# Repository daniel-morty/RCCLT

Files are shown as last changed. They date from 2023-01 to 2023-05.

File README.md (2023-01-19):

# ESPNOW Basic Example

This is a very basic example to get up and running with ESP-NOW using ESP-IDF. While the included example in the IDF is comprehensive and secure, this example should allow for faster understanding and testing.

The slave will simply send a random value and the state of GPIO 0 (typically attached to a button named '0', 'BOOT' or 'PROG' on most dev boards) to the broadcast address. The master will receive and log it.

To customise the payload, simply change the struct in espnow_basic_config.h, and edit my_slave.c and my_master.c to populate and parse respectively.

See espnow_basic_config.h for more.

============================================================
mac of remote/car pair 1
remote	f4:12:fa:1b:3e:b0
car:	f4:12:fa:1b:84:88

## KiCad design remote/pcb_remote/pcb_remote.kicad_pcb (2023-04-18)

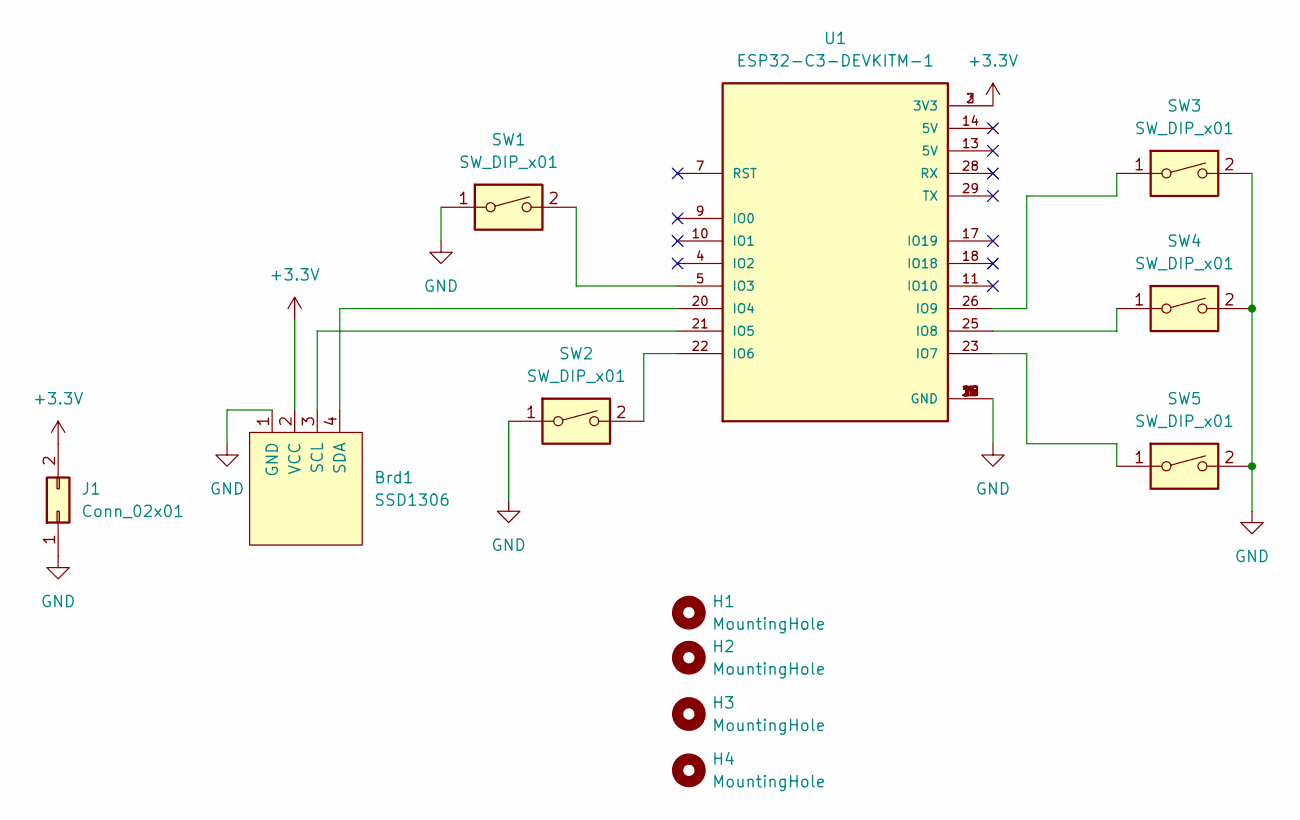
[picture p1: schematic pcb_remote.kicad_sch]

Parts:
Brd1: SSD1306; 128x64OLED
H1, H2, H3, H4: MountingHole; MountingHole_2.2mm_M2
J1: Conn_02x01; PinHeader_1x02_P2.54mm_Vertical
SW1, SW2, SW3, SW4, SW5: SW_DIP_x01; SW_PUSH-12mm
U1: ESP32-C3-DEVKITM-1; XCVR_ESP32-C3-DEVKITM-1

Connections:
+3V3: Brd1.2 (VCC), J1.2, U1.2 (3V3), U1.3 (3V3)
GND: Brd1.1 (GND), J1.1, SW1.1, SW2.1, SW3.2, SW4.2, SW5.2, U1.1 (GND), U1.6 (GND), U1.8 (GND), U1.12 (GND), U1.15 (GND), U1.16 (GND), U1.19 (GND), U1.24 (GND), U1.27 (GND), U1.30 (GND)
unnamed: Brd1.3 (SCL), U1.21 (IO5)
unnamed: Brd1.4 (SDA), U1.20 (IO4)
unnamed: SW1.2, U1.5 (IO3)
unnamed: SW2.2, U1.22 (IO6)
unnamed: SW3.1, U1.26 (IO9)
unnamed: SW4.1, U1.25 (IO8)
unnamed: SW5.1, U1.23 (IO7)

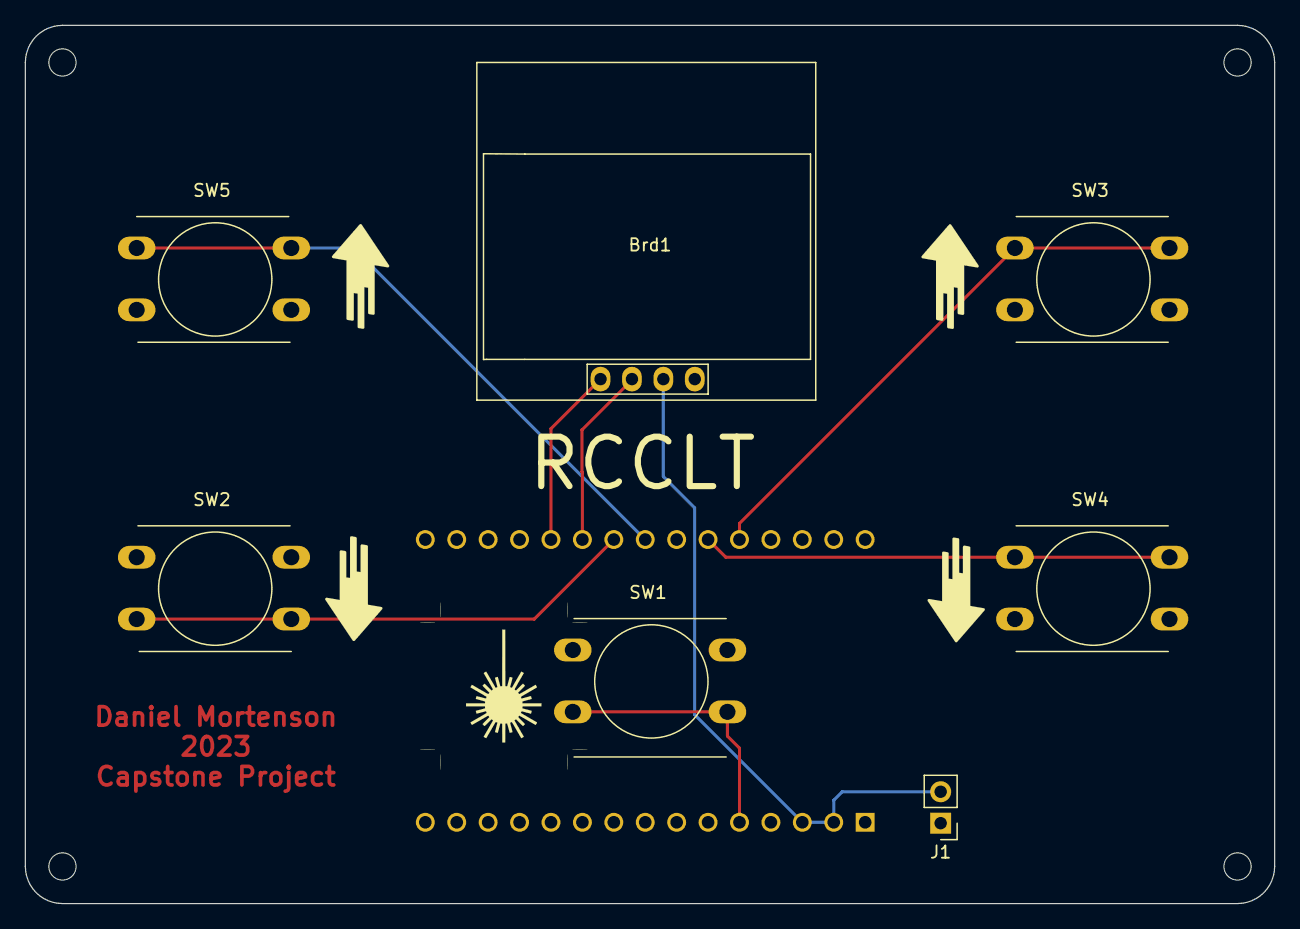
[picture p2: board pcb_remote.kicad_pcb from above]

Board: 2 copper layers, 101.0 x 71.0 mm, 12 parts (1 on the bottom side), 9 nets.

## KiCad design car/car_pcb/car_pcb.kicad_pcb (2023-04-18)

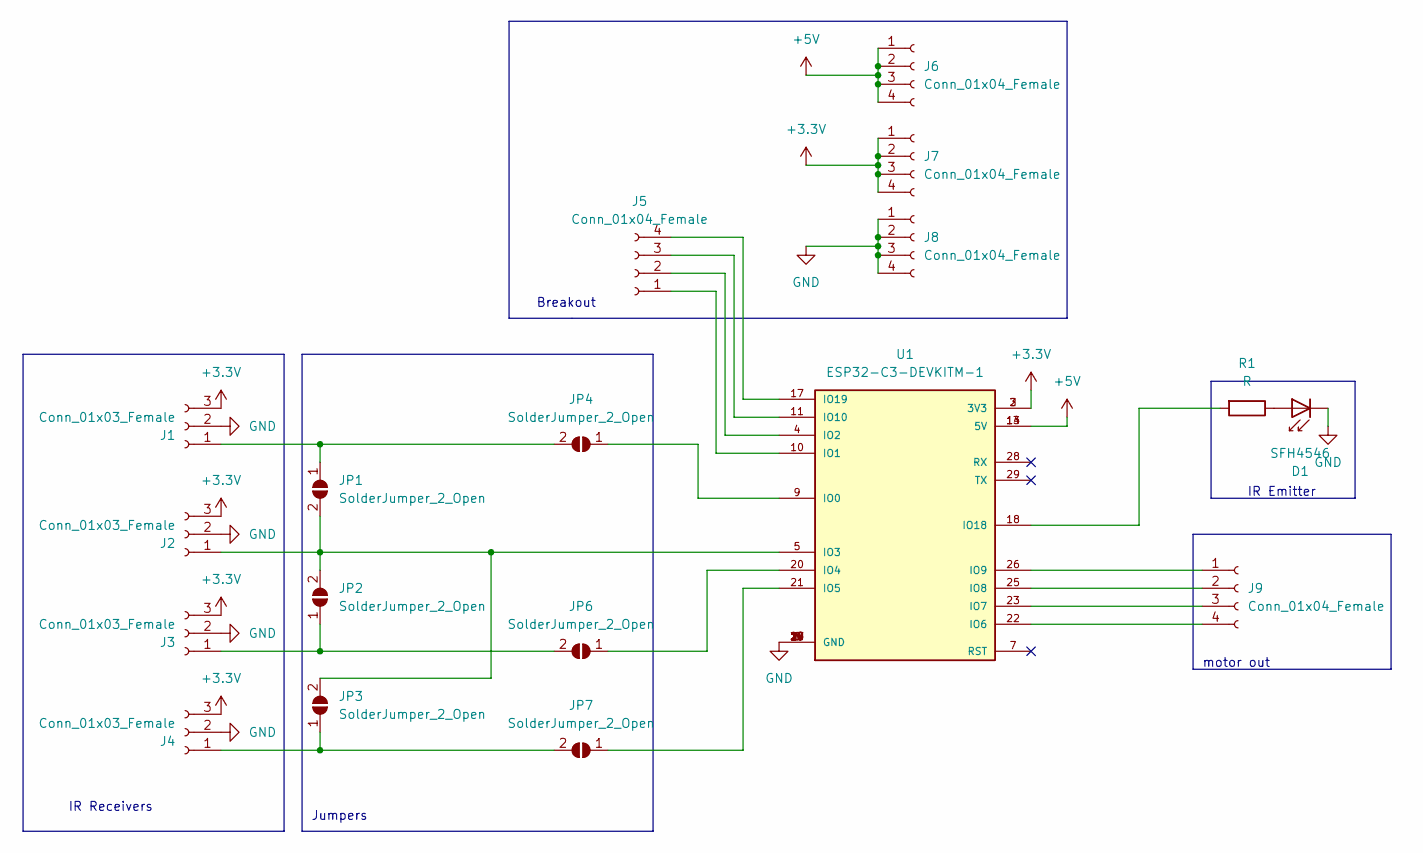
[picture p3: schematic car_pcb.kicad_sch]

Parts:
D1: SFH4546; LED_D5.0mm_IRGrey
J1, J2, J3, J4: Conn_01x03_Female; PinHeader_1x03_P2.54mm_Vertical
J5, J6, J7, J8, J9: Conn_01x04_Female; PinHeader_1x04_P2.54mm_Vertical
JP1, JP2, JP3: SolderJumper_2_Open; SolderJumper-2_P1.3mm_Open_TrianglePad1.0x1.5mm
JP4, JP6, JP7: SolderJumper_2_Open; SolderJumper-2_P1.3mm_Bridged_Pad1.0x1.5mm
R1: R; R_Axial_DIN0207_L6.3mm_D2.5mm_P10.16mm_Horizontal
U1: ESP32-C3-DEVKITM-1; XCVR_ESP32-C3-DEVKITM-1

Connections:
+3V3: J1.3, J2.3, J3.3, J4.3, J7.1, J7.2, J7.3, J7.4, U1.2 (3V3), U1.3 (3V3)
+5V: J6.1, J6.2, J6.3, J6.4, U1.13 (5V), U1.14 (5V)
GND: D1.1 (K), J1.2, J2.2, J3.2, J4.2, J8.1, J8.2, J8.3, J8.4, U1.1 (GND), U1.6 (GND), U1.8 (GND), U1.12 (GND), U1.15 (GND), U1.16 (GND), U1.19 (GND), U1.24 (GND), U1.27 (GND), U1.30 (GND)
unnamed: D1.2 (A), R1.1
unnamed: J1.1, JP1.1 (A), JP4.2 (B)
unnamed: J2.1, JP1.2 (B), JP2.2 (B), JP3.2 (B), U1.5 (IO3)
unnamed: J3.1, JP2.1 (A), JP6.2 (B)
unnamed: J4.1, JP3.1 (A), JP7.2 (B)
unnamed: J5.1, U1.10 (IO1)
unnamed: J5.2, U1.4 (IO2)
unnamed: J5.3, U1.11 (IO10)
unnamed: J5.4, U1.17 (IO19)
unnamed: J9.1, U1.26 (IO9)
unnamed: J9.2, U1.25 (IO8)
unnamed: J9.3, U1.23 (IO7)
unnamed: J9.4, U1.22 (IO6)
unnamed: JP4.1 (A), U1.9 (IO0)
unnamed: JP6.1 (A), U1.20 (IO4)
unnamed: JP7.1 (A), U1.21 (IO5)
unnamed: R1.2, U1.18 (IO18)

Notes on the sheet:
IR Receivers
IR Emitter
Breakout
motor out
Jumpers

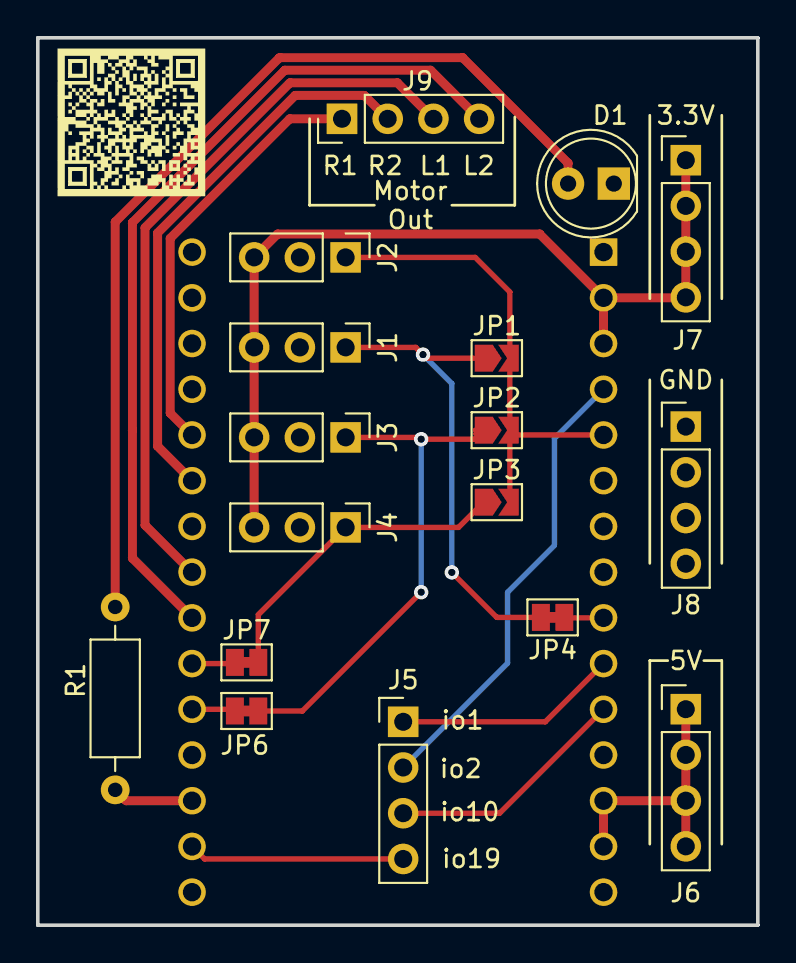
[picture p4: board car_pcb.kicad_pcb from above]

Board: 2 copper layers, 40.0 x 49.3 mm, 18 parts (1 on the bottom side), 20 nets.

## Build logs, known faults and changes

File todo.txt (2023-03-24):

REMOTE
==================================================================================================

CAR
==================================================================================================
- move all the functinos in ir_transiever.h to ir_transiever.c (be consistent)
-clean up ir code in main. It's horrendous and causes errors that take up time
	- is there a way to get rid of the RTOS? It's slow.
		-maybe the while loop in main should just be empty
	- order more of the correct resistor for the IR led
-I don't like that I'm setting a global variable to shoot the laser from the main loop.
	- can that be changed to be called when the packet is recieved?

SCORE_BOARD
==================================================================================================
- create website

GENERAL
==================================================================================================
- get ip addresses of more car remote pairs
- clean up code, comment code, have some class
- actually make it be a game

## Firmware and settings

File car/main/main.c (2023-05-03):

#define CONFIG_FREERTOS_ENABLE_BACKWARD_COMPATIBILITY 1

#include <stdlib.h>
#include <string.h>
#include "freertos/FreeRTOS.h"
#include "freertos/task.h"
#include "freertos/queue.h"
#include "nvs_flash.h"
#include "esp_event.h"
#include "esp_netif.h"
#include "esp_wifi.h"
#include "esp_log.h"
#include "esp_system.h"
#include "esp_now.h"
#include "driver/gpio.h"
#include "driver/rmt.h"

#include "esp_now_custom.h"

#include "sdkconfig.h"

#include "espnow_basic_config.h"

#define OUT_PIN_SEL ((1ULL<<RF_PIN) | (1ULL<<RB_PIN) | (1ULL<<LF_PIN) | (1ULL<<LB_PIN) | (1ULL<<LASER_PIN))

static const char *TAG = "car";
rmt_item32_t items [8];


void car_hit(uint8_t car_shooting);

void ir_rx_task(void *arg) {
    uint8_t data;
    RingbufHandle_t rb = NULL;

    // Get the RMT RX ring buffer
    rmt_get_ringbuf_handle(RMT_RX_CHANNEL, &rb);
    rmt_rx_start(RMT_RX_CHANNEL, 1);

    while (1) {
        size_t rx_size = 0;
        rmt_item32_t *received_items = (rmt_item32_t *)xRingbufferReceive(rb, &rx_size, portMAX_DELAY);
		ESP_LOGI(TAG, "items received");
        if (received_items) {
            int num_items = rx_size / sizeof(rmt_item32_t);
			ESP_LOGI(TAG, "NUM ITEMS: %d", num_items);

            data = 0;
			ESP_LOGI(TAG, "before for loop");
            for (int i = 0; i < 8 && i < num_items; ++i) {
                if (received_items[i].level0 == 0 && received_items[i].level1 == 1) {
					ESP_LOGI(TAG, "bit %d receiverd", i);
					ESP_LOGI(TAG, "DURATION 0 : %d", received_items[i].duration0);
					ESP_LOGI(TAG, "DURATION 1 : %d", received_items[i].duration1);
                    if (received_items[i].duration0 > 500 && received_items[i].duration0 > 1500 && received_items[i].duration1 < 1500) {
                        data |= (1 << i);
                    }
                }
            }
			ESP_LOGI(TAG, "after first for loop");
			ESP_LOGI(TAG, "data receiverd %x\n\n", data);
			switch(data){
				case 0xfc:	//Inky
					if (CAR_REMOTE_PAIR != INKY) car_hit(INKY);
					break;
				case 0xf9:	//BLINKY
					if (CAR_REMOTE_PAIR != BLINKY) car_hit(BLINKY);
					break;
				case 0xf3:	//PINKY
					if (CAR_REMOTE_PAIR != PINKY) car_hit(PINKY);
					break;
				case 0xe7:	//CLYDE
					if (CAR_REMOTE_PAIR != CLYDE) car_hit(CLYDE);
					break;
				default:
					break;
			}

            // Check if stop bit is valid
            //if (num_items >= 9 && received_items[8].level0 == 1 && received_items[8].level1 == 0 && received_items[8].duration0 > 1500 && received_items[8].duration1 > 500 && received_items[8].duration1 < 1500) {
            //    car_hit(data);
            //}

            // Free the memory allocated for received_items
            vRingbufferReturnItem(rb, (void *)received_items);
			ESP_LOGI(TAG, "after memory is freed");
        }
    }
}

static void IR_init(){
	//initialize IR receiving
	rmt_config_t rmt_tx_config = {
		.channel = RMT_TX_CHANNEL,
		.gpio_num = LASER_PIN,
		.clk_div = 150,
		.rmt_mode = RMT_MODE_TX,
		.tx_config = {
			.carrier_freq_hz = 38000,
			.carrier_duty_percent = 50,
			.carrier_level = RMT_CARRIER_LEVEL_HIGH,
			.carrier_en = true,
			.loop_en = false,
			.idle_level = RMT_IDLE_LEVEL_LOW,
			.idle_output_en = true,
		},
		.mem_block_num = 1,
	};

	rmt_config_t rmt_rx_config = {
		.channel = RMT_RX_CHANNEL,
		.gpio_num = IR_RX_PIN,
		.clk_div = 150,
		.rmt_mode = RMT_MODE_RX,
		.rx_config = {
			.carrier_freq_hz = 38000,
			.carrier_duty_percent = 50,
			.carrier_level = RMT_CARRIER_LEVEL_HIGH,
			.rm_carrier = true,
			.filter_ticks_thresh = 100,
			.filter_en = true,
			.idle_threshold = 12000,
		},
		.mem_block_num = 1,
	};
	
	ESP_LOGI(TAG, "init tx channel");
	ESP_ERROR_CHECK(rmt_config(&rmt_tx_config));
	ESP_ERROR_CHECK(rmt_driver_install(rmt_tx_config.channel, 0, 0));
	ESP_LOGI(TAG, "init rx channel");
	ESP_ERROR_CHECK(rmt_config(&rmt_rx_config));
	ESP_ERROR_CHECK(rmt_driver_install(rmt_rx_config.channel, 1000, 0));


	//start the RMT receiver
	rmt_rx_start(RMT_RX_CHANNEL, true);

	//create IR receive task
	xTaskCreate(ir_rx_task, "ir_rx_task", 2048, NULL, tskIDLE_PRIORITY, NULL);
	

	//create the message for shooting it later
	uint8_t data;
	switch(CAR_REMOTE_PAIR){
		case INKY:
			data = 2;
			break;
		case BLINKY:
			data = 4;
			break;
		case PINKY:
			data = 8;
			break;
		case CLYDE:
			data = 16;
			break;
		default:
			data = 255;
	}
	memset(items, 0, sizeof(items));

	for(int i=0; i<8; ++i){
		if(data & (1 << i)){
			items[i].duration0 = 2000;
			items[i].level0 = 0;
			items[i].duration1 = 1000;
			items[i].level1 = 1;
		} else {
			items[i].duration0 = 1000;
			items[i].level0 = 0;
			items[i].duration1 = 2000;
			items[i].level1 = 1;
		}
	}
		//items[8].duration0 = 1000;
		//items[8].level0 = 0;
		//items[8].duration1 = 2000;
		//items[8].level1 = 1;

	for(int i=0; i<8; i++){
		ESP_LOGI(TAG, "BIT %d", i);
		ESP_LOGI(TAG, "duration 0: %d", items[i].duration0);
		ESP_LOGI(TAG, "duration 1: %d", items[i].duration1);
		ESP_LOGI(TAG, "");
	}
}

void car_hit(uint8_t car_shooting){ //file ????
	my_data_t data;
	data.message_type = HIT_REPORT;
	data.car_shooting = car_shooting;//TODO get id of car shooting
	data.car_shot = CAR_ID;

	//send it
	ESP_LOGI(TAG, "sending hit report");
	esp_err_t err = send_espnow_data(data);
	if(err != ESP_OK){
	ESP_LOGE(TAG, "error sending hit_report message");
	}
	return;
}





void app_main(void)
{

    //zero-initialize the config structure.
    gpio_config_t io_conf = {};
    //disable interrupt
    io_conf.intr_type = GPIO_INTR_DISABLE;
    //set as output mode
    io_conf.mode = GPIO_MODE_OUTPUT;
    //bit mask of the pins that yo_want to set
    io_conf.pin_bit_mask = OUT_PIN_SEL;
    //disable pull-down mode
    io_conf.pull_down_en = 0;
    //disable pull-up mode
    io_conf.pull_up_en = 0;
    //configure GPIO with the given settings
    gpio_config(&io_conf);

    
	//init espnow
    init_espnow_master();

	//init ir
	vTaskDelay(2000 /portTICK_PERIOD_MS);
	IR_init();


	ESP_LOGI(TAG, "before main loop");
	while(1){
		//gpio_set_level(RF_PIN, 0);
		//gpio_set_level(RB_PIN, 0);
		//gpio_set_level(LF_PIN, 0);
		//gpio_set_level(LB_PIN, 0);
		vTaskDelay(750 / portTICK_PERIOD_MS);	
	}

}

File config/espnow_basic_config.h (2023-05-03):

#ifndef ESPNOW_BASIC_CONFIG_H
#define ESPNOW_BASIC_CONFIG_H

#include <inttypes.h>
#include <stdbool.h>

#define INKY	1
#define BLINKY	2
#define PINKY	3
#define CLYDE	4
//change this value to compile for different care remote pairs
#define CAR_REMOTE_PAIR CLYDE

#define RF_PIN 9
#define RB_PIN 8
#define LF_PIN 7
#define LB_PIN 6
#define LASER_PIN 18
#define IR_RX_PIN 3
#define PWM_PIN 19

#define RMT_TX_CHANNEL RMT_CHANNEL_0
#define RMT_RX_CHANNEL RMT_CHANNEL_2

#define RF_BUT 9
#define RB_BUT 8
#define LF_BUT 7
#define LB_BUT 6
#define LASER_BUT 3

//message types
#define CAR_COMMAND  1
#define HIT_REPORT   2
#define SCORE_UPDATE 3


typedef struct {
	int score;
	int life_points;
} score_t;

// Define the structure of your data
typedef struct __attribute__((packed)) {
	//message type
	uint8_t message_type;

	//commands to the car
	//use if message type is CAR_COMMAND
    bool rf;
    bool rb;
    bool lf;
    bool lb;
	bool shoot_laser;

	//hit report 
	//use if mssage type is HIT_REPORT
	uint8_t car_shooting;
	uint8_t car_shot;

	//score update
	//use if message type is SCORE_UPDATE
	int updated_score;
	int updated_life_points;
	uint8_t car_id;
} my_data_t;

#define SCORE_BOARD_MAC {0x58, 0xcf, 0x79, 0xe9, 0xc3, 0x5d}

//INKY
#define PAIR_1_CAR_MAC		{0xec, 0xda, 0x3b, 0x0f, 0x20, 0x44}
#define PAIR_1_REMOTE_MAC	{0x34, 0x85, 0x18, 0x23, 0x7e, 0xb0}
#define PAIR_1_REMOTE_MAC_ARR	(uint8_t[])PAIR_1_REMOTE_MAC

//BLINKY
#define PAIR_2_CAR_MAC		{0xf4, 0x12, 0xfa, 0x1b, 0x8a, 0x30}
#define PAIR_2_REMOTE_MAC	{0x48, 0x27, 0xe2, 0xad, 0x03, 0x60}
#define PAIR_2_REMOTE_MAC_ARR	(uint8_t[])PAIR_2_REMOTE_MAC

//PINKY
#define PAIR_3_CAR_MAC		{0x48, 0x27, 0xe2, 0xad, 0x92, 0x30}
#define PAIR_3_REMOTE_MAC	{0xec, 0xda, 0x3b, 0x0e, 0xfd, 0xe0}
#define PAIR_3_REMOTE_MAC_ARR	(uint8_t[])PAIR_3_REMOTE_MAC

//CLYDE
#define PAIR_4_CAR_MAC		{0x34, 0x85, 0x18, 0x21, 0x8c, 0xc4}
#define PAIR_4_REMOTE_MAC	{0x34, 0x85, 0x18, 0x23, 0x76, 0xf4}
#define PAIR_4_REMOTE_MAC_ARR	(uint8_t[])PAIR_4_REMOTE_MAC

#if CAR_REMOTE_PAIR == INKY
	#define CAR_MAC		PAIR_1_CAR_MAC	 
	#define REMOTE_MAC	PAIR_1_REMOTE_MAC
	#define CAR_ID 1
	#define REMOTE_ID 1

#elif CAR_REMOTE_PAIR == BLINKY
	#define CAR_MAC		PAIR_2_CAR_MAC	 
	#define REMOTE_MAC	PAIR_2_REMOTE_MAC
	#define CAR_ID 2
	#define REMOTE_ID 2

#elif CAR_REMOTE_PAIR == PINKY
	#define CAR_MAC		PAIR_3_CAR_MAC	 
	#define REMOTE_MAC	PAIR_3_REMOTE_MAC
	#define CAR_ID 3
	#define REMOTE_ID 3

#elif CAR_REMOTE_PAIR == CLYDE
	#define CAR_MAC		PAIR_4_CAR_MAC	 
	#define REMOTE_MAC	PAIR_4_REMOTE_MAC
	#define CAR_ID 4
	#define REMOTE_ID 4
#endif

#define MY_ESPNOW_PMK "pmk1234567890123"
#define MY_ESPNOW_CHANNEL 1

// #define MY_ESPNOW_ENABLE_LONG_RANGE 1

#define MY_SLAVE_DEEP_SLEEP_TIME_MS 1000

#define STARTING_LIFE_POINTS 9

#endif // ESPNOW_BASIC_CONFIG_H

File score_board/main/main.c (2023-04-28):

#define CONFIG_FREERTOS_ENABLE_BACKWARD_COMPATIBILITY 1

#include <stdlib.h>
#include <string.h>
#include "freertos/FreeRTOS.h"
#include "freertos/task.h"
#include "freertos/queue.h"
#include "nvs_flash.h"
#include "esp_event.h"
#include "esp_netif.h"
#include "esp_wifi.h"
#include "esp_log.h"
#include "esp_system.h"
#include "esp_now.h"
#include "driver/gpio.h"

#include "sdkconfig.h"

#include "espnow_basic_config.h"
#include "webserver.h"

#define OUT_PIN_SEL ((1ULL<<RF_PIN) | (1ULL<<RB_PIN) | (1ULL<<LF_PIN) | (1ULL<<LB_PIN) | (1ULL<<LASER_PIN))

static const char *TAG = "score_board";
bool shoot_laser;

//extern static const httpd_uri_t hello;

static esp_err_t send_espnow_data(my_data_t data);

typedef struct {
    uint8_t sender_mac_addr[ESP_NOW_ETH_ALEN];
    my_data_t data;
} recv_packet_t;

//set up data structure for keeping score
score_t scores[4];

//#define MY_ESPNOW_WIFI_MODE WIFI_MODE_STA
//#define MY_ESPNOW_WIFI_IF   ESP_IF_WIFI_STA
 #define MY_ESPNOW_WIFI_MODE WIFI_MODE_AP
 #define MY_ESPNOW_WIFI_IF   ESP_IF_WIFI_AP

void log_scores(){
	for(int i=0; i<4; i++){
		ESP_LOGI(TAG, "car %d\tscore: %d\tlife_points: %d", i, scores[i].score, scores[i].life_points);
	}
}

static void send_reports(uint8_t car_shot, uint8_t car_shooting){
	//send updates to the remotes of the cars
	my_data_t data;
	data.message_type = SCORE_UPDATE;
	ESP_LOGI(TAG, "sending reports to %d[shot] and %d[shooter]", car_shot, car_shooting);

	//send update to car that was shot
	data.updated_score = scores[car_shot-1].score;						
	scores[car_shot-1].life_points = scores[car_shot-1].life_points - 1; //decrement life points
	data.updated_life_points = scores[car_shot-1].life_points;
	data.car_id = car_shot;
	send_espnow_data(data);


	//send update to car that fired the shot
	scores[car_shooting-1].score = scores[car_shooting-1].score + 1;		//increment score
	data.updated_score = scores[car_shooting-1].score;						
	data.updated_life_points = scores[car_shooting-1].life_points;
	data.car_id = car_shooting;
	send_espnow_data(data);
	
	log_scores();
	
	return;
}

static void recv_cb(const uint8_t *mac_addr, const uint8_t *data, int len)
{
	//TODO clean this up, log data
	ESP_LOGI(TAG, "in recv_cb");
    
    if(len != sizeof(my_data_t))
    {
        ESP_LOGE(TAG, "Unexpected data length: %d != %u", len, sizeof(my_data_t));
        return;
    }

	//move the car accordingly
	my_data_t *packet = data; //!note this line generates a warning. it works fine though
								//because we checked the length above

	if(packet->message_type != HIT_REPORT){
		ESP_LOGE(TAG, "wrong message_type recieved");
	} else{
		send_reports(packet->car_shot, packet->car_shooting); //update scores and foreward to remotes
	}

    //ESP_ERROR_CHECK(rmt_receive(rx_channel, raw_symbols, sizeof(raw_symbols), &receive_config));
	return;
}

static esp_err_t send_espnow_data(my_data_t data)
{
	//TODO log data

	//const uint8_t destination_mac[] = {0xf4, 0x12, 0xfa, 0x1b, 0x3e, 0xb0};
	uint8_t destination_mac[6];
	switch(data.car_id){
		case 1:
			for(int i=0; i<6; i++){
				destination_mac[i] = PAIR_1_REMOTE_MAC_ARR[i];
			}
		break;
		case 2:
			for(int i=0; i<6; i++){
				destination_mac[i] = PAIR_2_REMOTE_MAC_ARR[i];
			}
		break;
		case 3:
			for(int i=0; i<6; i++){
				destination_mac[i] = PAIR_3_REMOTE_MAC_ARR[i];
			}
		break;
		case 4:
			for(int i=0; i<6; i++){
				destination_mac[i] = PAIR_4_REMOTE_MAC_ARR[i];
			}
		break;
	}

		ESP_LOGI(TAG, "sending to %d", data.car_id);
		for(int i=0; i<6; i++){
			ESP_LOGI(TAG, "%x", destination_mac[i]);
		}
		ESP_LOGI(TAG, "");

    // Send it
	esp_err_t err = esp_now_send(destination_mac, (uint8_t*)&data, sizeof(data));
    if(err != ESP_OK)
    {
        ESP_LOGE(TAG, "Send error (%d)", err);
        return ESP_FAIL;
    }


    ESP_LOGI(TAG, "Sent!");
    return ESP_OK;
}

static void init_espnow_master(void)
{
    const wifi_init_config_t cfg = WIFI_INIT_CONFIG_DEFAULT();
    esp_err_t ret = nvs_flash_init();
    if (ret == ESP_ERR_NVS_NO_FREE_PAGES || ret == ESP_ERR_NVS_NEW_VERSION_FOUND) {
        ESP_ERROR_CHECK( nvs_flash_erase() );
        ret = nvs_flash_init();
    }
    ESP_ERROR_CHECK( ret );
    ESP_ERROR_CHECK( esp_netif_init());
    ESP_ERROR_CHECK( esp_event_loop_create_default() );
    ESP_ERROR_CHECK( esp_wifi_init(&cfg) );
    ESP_ERROR_CHECK( esp_wifi_set_storage(WIFI_STORAGE_RAM) );
    ESP_ERROR_CHECK( esp_wifi_set_mode(MY_ESPNOW_WIFI_MODE) );
    ESP_ERROR_CHECK( esp_wifi_start() );
#if MY_ESPNOW_ENABLE_LONG_RANGE
    ESP_ERROR_CHECK( esp_wifi_set_protocol(MY_ESPNOW_WIFI_IF, WIFI_PROTOCOL_11B|WIFI_PROTOCOL_11G|WIFI_PROTOCOL_11N|WIFI_PROTOCOL_LR) );
#endif
    ESP_ERROR_CHECK( esp_now_init() );
    ESP_ERROR_CHECK( esp_now_register_recv_cb(recv_cb) );
    ESP_ERROR_CHECK( esp_now_set_pmk((const uint8_t *)MY_ESPNOW_PMK) );

    const esp_now_peer_info_t broadcast_destination1 = {
        .peer_addr = PAIR_1_REMOTE_MAC,
        .channel = MY_ESPNOW_CHANNEL,
        .ifidx = MY_ESPNOW_WIFI_IF
    };
    ESP_ERROR_CHECK( esp_now_add_peer(&broadcast_destination1) );

    const esp_now_peer_info_t broadcast_destination2 = {
        .peer_addr = PAIR_2_REMOTE_MAC,
        .channel = MY_ESPNOW_CHANNEL,
        .ifidx = MY_ESPNOW_WIFI_IF
    };
    ESP_ERROR_CHECK( esp_now_add_peer(&broadcast_destination2) );

    const esp_now_peer_info_t broadcast_destination3 = {
        .peer_addr = PAIR_3_REMOTE_MAC,
        .channel = MY_ESPNOW_CHANNEL,
        .ifidx = MY_ESPNOW_WIFI_IF
    };
    ESP_ERROR_CHECK( esp_now_add_peer(&broadcast_destination3) );

    const esp_now_peer_info_t broadcast_destination4 = {
        .peer_addr = PAIR_4_REMOTE_MAC,
        .channel = MY_ESPNOW_CHANNEL,
        .ifidx = MY_ESPNOW_WIFI_IF
    };
    ESP_ERROR_CHECK( esp_now_add_peer(&broadcast_destination4) );
}
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

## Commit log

2023-01-19 trim rtos, buttons control motor
2023-01-20 add laser shoot capability
2023-01-31 add more mac addresses, and easy way to switch car/remote pair
2023-01-31 car shoots laser, need to call get hit function
2023-03-08 fix automatic sending of score_update
    [main.c]
2023-03-24 add interrupts to remote
2023-03-30 fix laser, add boot text
    [main.c]
2023-04-18 add pcb files
    [car_pcb.kicad_pcb, car_pcb.kicad_sch, pcb_remote.kicad_pcb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]
2023-04-28 change laser protocol, other error fixes
    [esp_now_custom.c, espnow_basic_config.h, main.c]
